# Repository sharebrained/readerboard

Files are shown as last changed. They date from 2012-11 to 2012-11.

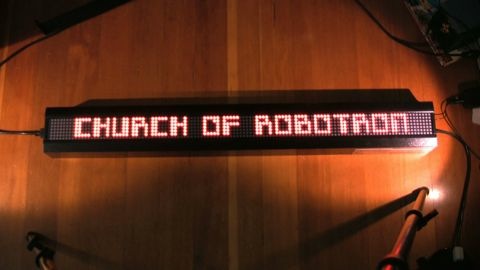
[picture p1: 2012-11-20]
documentation/photos/robotron_readerboard.jpg

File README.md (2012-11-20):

readerboard
===========

Some programmable LED signs have proprietary protocols, relegating these
otherwise fine and useful pieces of hardware to the scrapheap. This project
aims to replace the hardware and software in these signs, giving them new
life.

Readerboard running Church of Robotron

Go troll eBay, buy a "broken" LED sign, and join the party!

Sub-Projects
============

* hardware/readerboard_avr8: Atmel AVR8-based replacement for Data Display
  Corporation controller board.

* firmware/readerboard_avr8: Atmel AVR8-based firmware for USB control of the
  hardware/readerboard_avr8 board.
  
* software/readerboard.py: Example host software for controlling the
  readerboard_avr8 hardware. This was the code that ran at the Church of
  Robotron at ToorCamp 2012.

Status
======

The AVR8-related board, firmware, and software have all been tested and work
well.

Requirements
============

* [EAGLE 5.11 Freeware, Light, Hobbyist, Standard, or Professional]
  (http://www.cadsoftusa.com/shop/pricing/)

Other Projects / Prior Art
==========================

[http://noisybox.net/electronics/LED_sign/]
[http://churchofrobotron.com/]

License
=======

Each sub-project specifies its own license.

Contact
=======

ShareBrained Technology, Inc.

<http://www.sharebrained.com/>

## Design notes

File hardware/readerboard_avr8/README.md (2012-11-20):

readerboard_avr8
================

Replacement controller hardware for interfacing with Data Display Corporation
LED readerboards based on Hitachi 6309 controllers.

Status
======

This board has been fabricated and tested, and works well. It is based on other
stable designs, and a prototype using an Arduino Leonardo.

Bill of Materials
=================

See readerboard_avr8_bom.csv.

Requirements
============

* [EAGLE 5.11 Freeware, Light, Hobbyist, Standard, or Professional]
  (http://www.cadsoftusa.com/shop/pricing/)

Files
=====

* readerboard_avr8.sch:

    Schematic for circuit board, drawn in EAGLE 5.11.

* readerboard_avr8_schematic.pdf:

    Schematic for circuit board, in Adobe PDF format.

* readerboard_avr8_bom.csv:

    List of components used in the circuit board, including recommended
    vendors.

* readerboard_avr8.brd:

    Circuit board layout, drawn in EAGLE 5.11.

* readerboard_avr8_laen2.cam:

    EAGLE CAM file used to generate Gerber RS-274X files for
    circuit board production via
    [Laen's two-layer PCB Order]
    (http://dorkbotpdx.org/wiki/pcb_order).
    
* readerboard_avr8_placements_top.cam

    Diagram of component placements on the top surface of the circuit
    board.
    
License
=======

Copyright (c) 2012, ShareBrained Technology, Inc.
All rights reserved.

This hardware design is licensed under a
[Creative Commons Attribution-ShareAlike 3.0 Unported License]
(http://creativecommons.org/licenses/by-sa/3.0/).

Contact
=======

ShareBrained Technology, Inc.

<http://www.sharebrained.com/>

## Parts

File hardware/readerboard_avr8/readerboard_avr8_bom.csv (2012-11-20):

Ref Des | Qty | Mfr | Mfr Part | Description | Vendor | Vendor Part
C1,2 | 2 | Kemet | C0603C270J5GACTU | CAP CER 27PF 50V 5% NP0 0603 | Digi-Key | 399-1054-1-ND
C3,4 | 2 | Murata | GRM188F51C105ZA01D | CAP CER 1UF 16V Y5V 0603 | Digi-Key | 490-1582-1-ND
C5,6 | 2 | Murata | GRM188F51C104ZA01D | CAP CER .1UF 16V Y5V 0603 | Digi-Key | 490-1577-1-ND
C7,8 |  |  |  | do not populate
F1 | 1 | Bourns | MF-NSMF050-2 | PTC RESETTABLE .50A 13.2V 1206 | Digi-Key | MF-NSMF050-2TR-ND
FB1 | 1 | TDK | MPZ1608S601A | FERRITE CHIP BEAD 600 OHM SMD | Digi-Key | 445-2205-1-ND
J1 | 1 | On Shore Technology | USB-B1KSW6 | CONN USB TYPE B VERTICAL WHITE | Digi-Key | ED2980-ND
J2 | 1 |  |  | 2 x 8 0.1” header
J3 | 1 |  |  | 1 x 3 0.1” header
J4 | 1 |  |  | 2 x 3 0.1” header
J6 | 1 |  |  | 2 x 3 0.1” header
R1,2 | 2 | Yageo | RC0603JR-0722RL | RES 22 OHM 1/10W 5% 0603 SMD | Digi-Key | 311-22GRCT-ND
R9 | 1 | Yageo | RC0603FR-0710KL | RES 10.0K OHM 1/10W 1% 0603 SMD | Digi-Key | 311-10.0KHRCT-ND
U1 | 1 | Atmel | AT90USB162-16AU | MCU AVR USB 16K FLASH 32-TQFP | Digi-Key | AT90USB162-16AU-ND
X1 | 1 | Abracon | ABLS-16.000MHZ-B2-T | CRYSTAL 16.000MHZ 18PF SMD | Digi-Key | 535-9071-1-ND

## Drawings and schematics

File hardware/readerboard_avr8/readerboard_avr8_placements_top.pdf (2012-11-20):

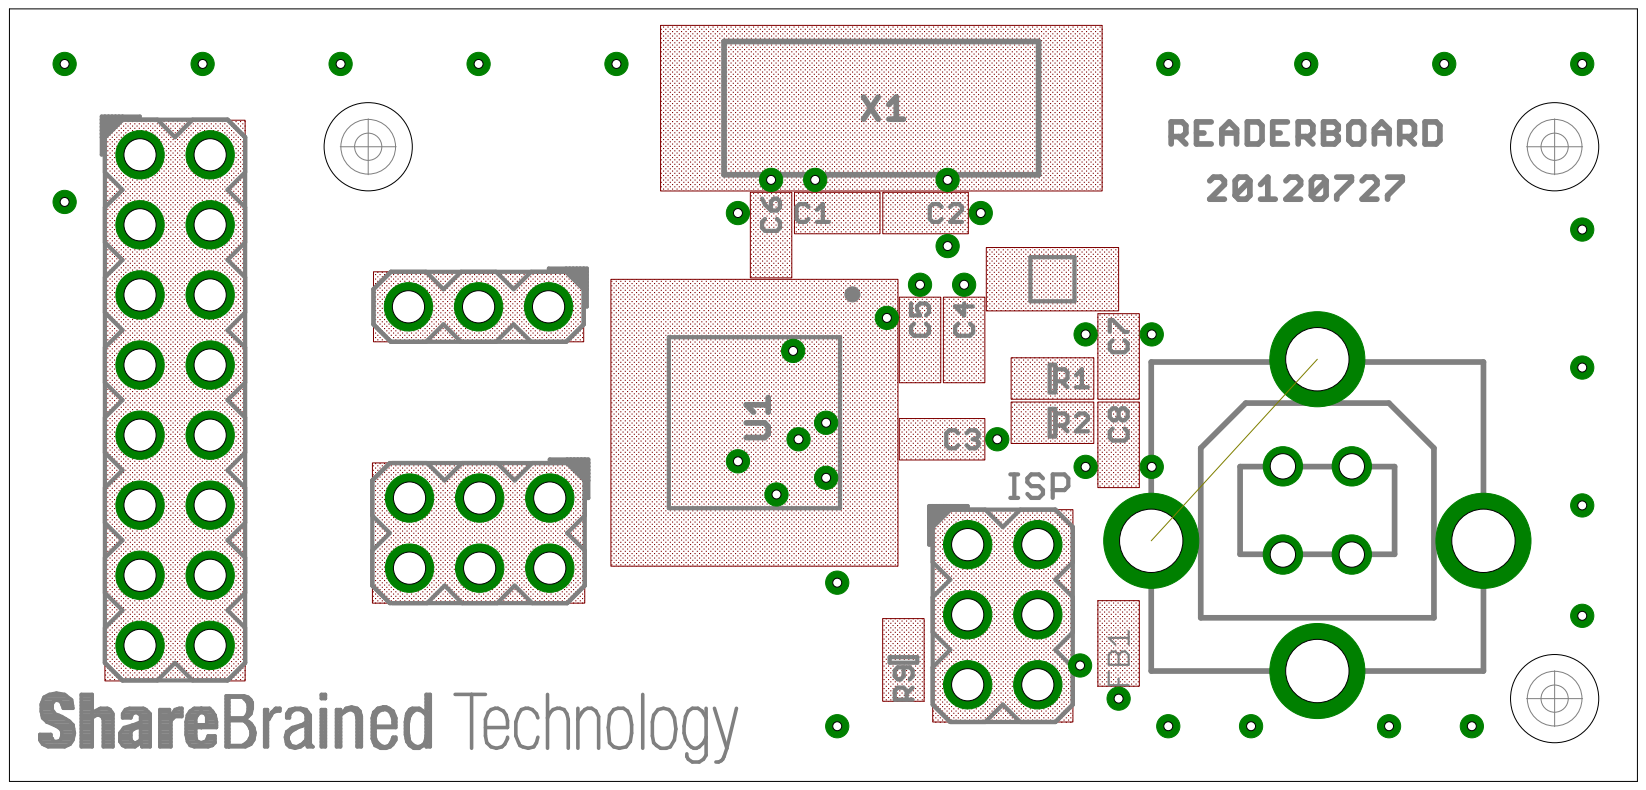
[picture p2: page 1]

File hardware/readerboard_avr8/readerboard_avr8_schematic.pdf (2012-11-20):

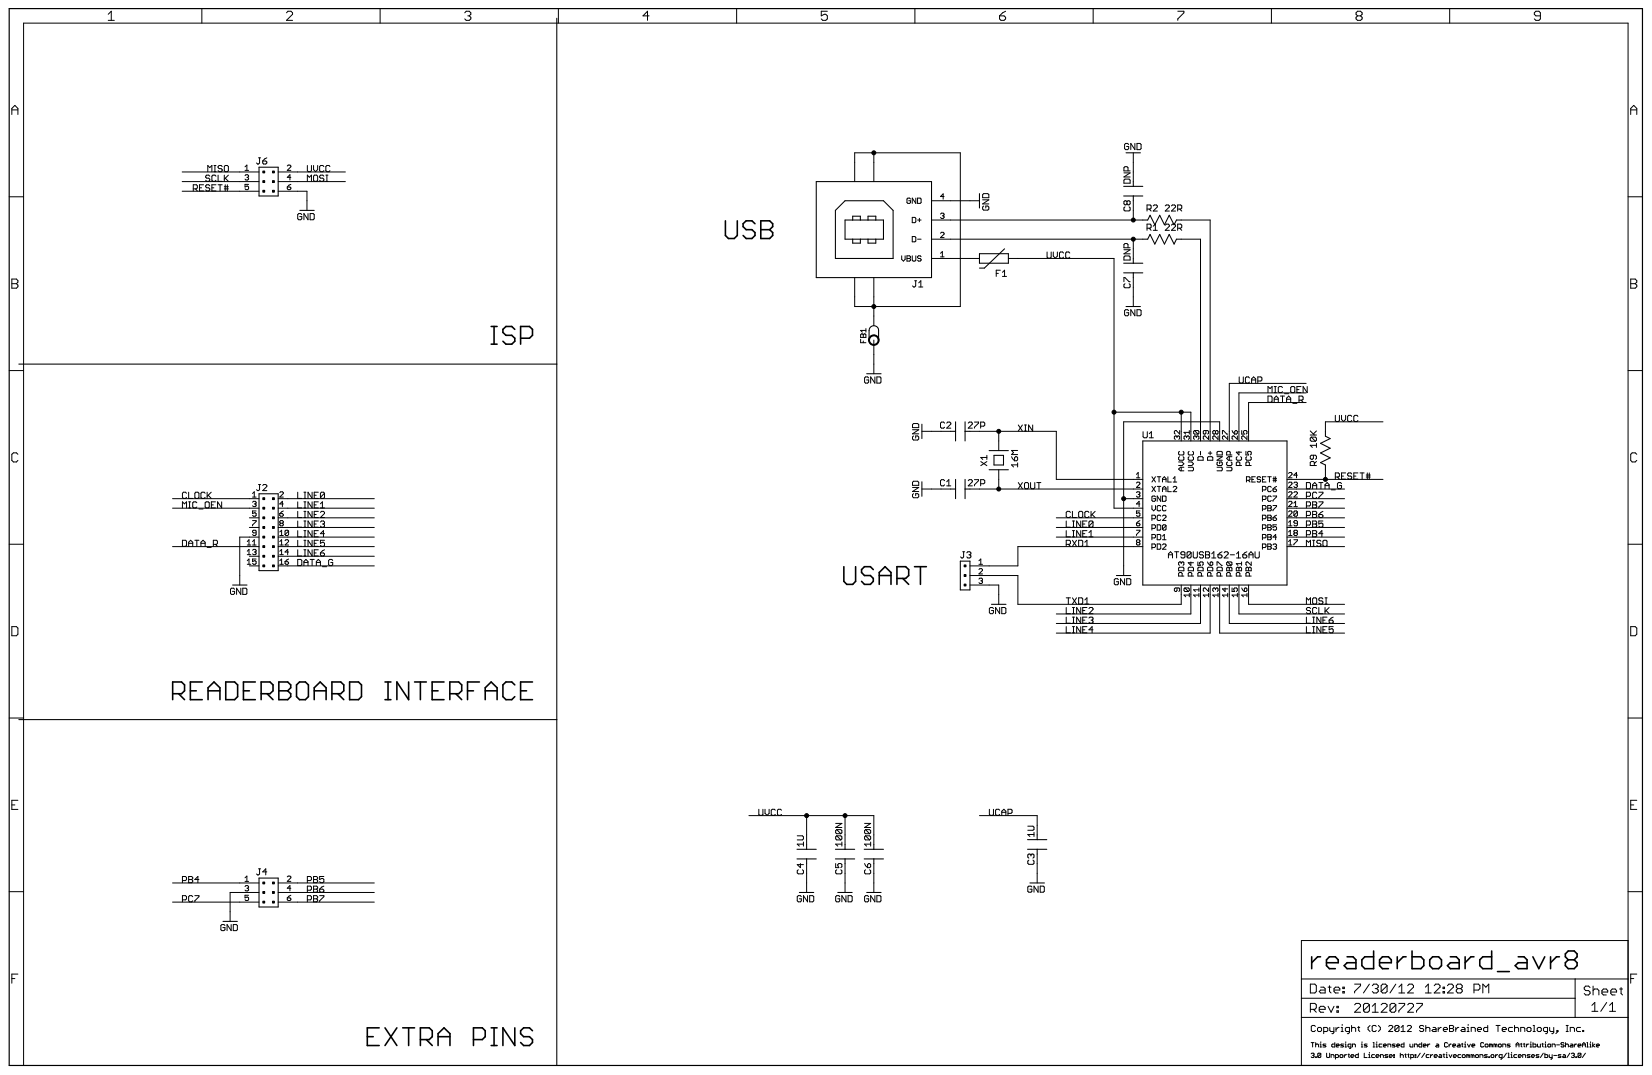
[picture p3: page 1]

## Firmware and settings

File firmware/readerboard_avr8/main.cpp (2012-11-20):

/*
 *
 * Copyright 2012 ShareBrained Technology, Inc.
 *
 * This file is part of readerboard.
 *
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
 */

#include "usb.h"
#include "usb_descriptor.h"

#include <stdint.h>
#include <stdbool.h>

#include <avr/io.h>
#include <avr/interrupt.h>

void Recv(volatile uint8_t* data, uint8_t count) {
	while (count--) {
		*data++ = UEDATX;
	}
}

int USB_RecvControl(void* d, int len)
{
	usb_wait_for_status_out();
	Recv((uint8_t*)d,len);
	usb_clear_out();
	return len;
}

typedef enum {
	DEVICE_STATE_UNINITIALIZED = 0,
	DEVICE_STATE_INITIALIZE_HARDWARE,
	DEVICE_STATE_FETCH_DATA,
	
	DEVICE_STATE_ERROR = 100,
} device_state_t;

#define DEVICE_STATE_FIRST_ERROR (DEVICE_STATE_ERROR)

static volatile device_state_t device_state = DEVICE_STATE_UNINITIALIZED;

static void configure_clocks() {
	/* PLL input prescaler: divide by 2 (16MHz / 2 = 8MHz)
	 */
	PLLCSR = _BV(PLLP0) | _BV(PLLE);
}

static void configure_power() {
	/* On: Timer/Counter0, Timer/Counter1
	 * Off: SPI
	 */
	PRR0 = _BV(PRSPI);
	
	/* On: USB, USART1
	 * Off: (none)
	 */
	//PRR1 = 0;
}

static void configure_pins() {
	MCUCR = 0;
	
	PORTB = 0;
	DDRB = _BV(0);
	
	PORTC = 0;
	DDRC = _BV(6) | _BV(5) | _BV(4) | _BV(2);
	
	PORTD = 0;
	DDRD = _BV(7) | _BV(6) | _BV(5) | _BV(4) | _BV(3) | _BV(1) | _BV(0);
}

static bool configure_hardware() {
	configure_clocks();
	configure_power();
	configure_pins();
	configure_usb();

	// Configure Timer 3 for ~ 60Hz * 7 (420Hz) interrupt rate.
	TCCR1A = 0;
	TCCR1C = 0;
	TCNT1 = 0;
	OCR1A = 38095;
	TIMSK1 = _BV(OCIE1A);
	TCCR1B = _BV(WGM12) | _BV(CS10);

	sei();

	usb_attach();
	
	return true;
}

void strobe_on(const uint8_t i) {
	switch(i) {
	case 0:
		PORTD |= _BV(0);
		break;
		
	case 1:
		PORTD |= _BV(1);
		break;
		
	case 2:
		PORTD |= _BV(4);
		break;
		
	case 3:
		PORTD |= _BV(5);
		break;
		
	case 4:
		PORTD |= _BV(6);
		break;
		
	case 5:
		PORTD |= _BV(7);
		break;
		
	case 6:
		PORTB |= _BV(0);
		break;
		
	default:
		break;
	}
}

void strobe_off(const uint8_t i) {
	switch(i) {
	case 0:
		PORTD &= ~(_BV(0));
		break;
		
	case 1:
		PORTD &= ~(_BV(1));
		break;
		
	case 2:
		PORTD &= ~(_BV(4));
		break;
		
	case 3:
		PORTD &= ~(_BV(5));
		break;
		
	case 4:
		PORTD &= ~(_BV(6));
		break;
		
	case 5:
		PORTD &= ~(_BV(7));
		break;
		
	case 6:
		PORTB &= ~(_BV(0));
		break;
		
	default:
		break;
	}
}

static const uint8_t sign_width = 120;
static const uint8_t sign_height = 7;

static const uint8_t sign_width_bytes = (sign_width + 7) / 8;

uint8_t data_r[2][sign_height][sign_width_bytes]; /* = {
	{
		{ 0xF8, 0x78, 0xF8, 0x78, 0xFC, 0xF8, 0x78, 0xF8, 0x00, 0x00, 0x00, 0x00, 0x00, 0x00, 0x00 },
		{ 0xCC, 0xCC, 0xCC, 0xCC, 0x30, 0xCC, 0xCC, 0xCC, 0x00, 0x00, 0x00, 0x00, 0x00, 0x00, 0x00 },
		{ 0xCC, 0xCC, 0xCC, 0xCC, 0x30, 0xCC, 0xCC, 0xCC, 0x00, 0x00, 0x00, 0x00, 0x00, 0x00, 0x00 },
		{ 0xF8, 0xCC, 0xF8, 0xCC, 0x30, 0xF8, 0xCC, 0xCC, 0x00, 0x00, 0x00, 0x00, 0x00, 0x00, 0x00 },
		{ 0xCC, 0xCC, 0xCC, 0xCC, 0x30, 0xCC, 0xCC, 0xCC, 0x00, 0x00, 0x00, 0x00, 0x00, 0x00, 0x00 },  
		{ 0xCC, 0xCC, 0xCC, 0xCC, 0x30, 0xCC, 0xCC, 0xCC, 0x00, 0x00, 0x00, 0x00, 0x00, 0x00, 0x00 },  
		{ 0xCC, 0x78, 0xF8, 0x78, 0x30, 0xCC, 0x78, 0xCC, 0x00, 0x00, 0x00, 0x00, 0x00, 0x00, 0x00 },
	},
	{
		{ 0xF8, 0x78, 0xF8, 0x78, 0xFC, 0xF8, 0x78, 0xF8, 0x00, 0x00, 0x00, 0x00, 0x00, 0x00, 0x00 },
		{ 0xCC, 0xCC, 0xCC, 0xCC, 0x30, 0xCC, 0xCC, 0xCC, 0x00, 0x00, 0x00, 0x00, 0x00, 0x00, 0x00 },
		{ 0xCC, 0xCC, 0xCC, 0xCC, 0x30, 0xCC, 0xCC, 0xCC, 0x00, 0x00, 0x00, 0x00, 0x00, 0x00, 0x00 },
		{ 0xF8, 0xCC, 0xF8, 0xCC, 0x30, 0xF8, 0xCC, 0xCC, 0x00, 0x00, 0x00, 0x00, 0x00, 0x00, 0x00 },
		{ 0xCC, 0xCC, 0xCC, 0xCC, 0x30, 0xCC, 0xCC, 0xCC, 0x00, 0x00, 0x00, 0x00, 0x00, 0x00, 0x00 },  
		{ 0xCC, 0xCC, 0xCC, 0xCC, 0x30, 0xCC, 0xCC, 0xCC, 0x00, 0x00, 0x00, 0x00, 0x00, 0x00, 0x00 },  
		{ 0xCC, 0x78, 0xF8, 0x78, 0x30, 0xCC, 0x78, 0xCC, 0x00, 0x00, 0x00, 0x00, 0x00, 0x00, 0x00 },
	},
};
*/
/*
uint8_t data_g[2][sign_height][sign_width_bytes]; = {
	{
		{ 0xF8, 0x00, 0x00, 0x00, 0x00, 0x00, 0x00, 0x00, 0x00, 0x00, 0x00, 0x00, 0x00, 0x00, 0x00 },
		{ 0xCC, 0x00, 0x00, 0x00, 0x00, 0x00, 0x00, 0x00, 0x00, 0x00, 0x00, 0x00, 0x00, 0x00, 0x00 },
		{ 0xCC, 0x00, 0x00, 0x00, 0x00, 0x00, 0x00, 0x00, 0x00, 0x00, 0x00, 0x00, 0x00, 0x00, 0x00 },
		{ 0xF8, 0x00, 0x00, 0x00, 0x00, 0x00, 0x00, 0x00, 0x00, 0x00, 0x00, 0x00, 0x00, 0x00, 0x00 },
		{ 0xCC, 0x00, 0x00, 0x00, 0x00, 0x00, 0x00, 0x00, 0x00, 0x00, 0x00, 0x00, 0x00, 0x00, 0x00 },
		{ 0xCC, 0x00, 0x00, 0x00, 0x00, 0x00, 0x00, 0x00, 0x00, 0x00, 0x00, 0x00, 0x00, 0x00, 0x00 },
		{ 0xCC, 0x00, 0x00, 0x00, 0x00, 0x00, 0x00, 0x00, 0x00, 0x00, 0x00, 0x00, 0x00, 0x00, 0x00 },
	},
	{
		{ 0xF8, 0x00, 0x00, 0x00, 0x00, 0x00, 0x00, 0x00, 0x00, 0x00, 0x00, 0x00, 0x00, 0x00, 0x00 },
		{ 0xCC, 0x00, 0x00, 0x00, 0x00, 0x00, 0x00, 0x00, 0x00, 0x00, 0x00, 0x00, 0x00, 0x00, 0x00 },
		{ 0xCC, 0x00, 0x00, 0x00, 0x00, 0x00, 0x00, 0x00, 0x00, 0x00, 0x00, 0x00, 0x00, 0x00, 0x00 },
		{ 0xF8, 0x00, 0x00, 0x00, 0x00, 0x00, 0x00, 0x00, 0x00, 0x00, 0x00, 0x00, 0x00, 0x00, 0x00 },
		{ 0xCC, 0x00, 0x00, 0x00, 0x00, 0x00, 0x00, 0x00, 0x00, 0x00, 0x00, 0x00, 0x00, 0x00, 0x00 },
		{ 0xCC, 0x00, 0x00, 0x00, 0x00, 0x00, 0x00, 0x00, 0x00, 0x00, 0x00, 0x00, 0x00, 0x00, 0x00 },
		{ 0xCC, 0x00, 0x00, 0x00, 0x00, 0x00, 0x00, 0x00, 0x00, 0x00, 0x00, 0x00, 0x00, 0x00, 0x00 },
	},
};
*/
PROGMEM const uint8_t character[64][7] = {
	{ 0b00000000, 0b00000000, 0b00000000, 0b00000000, 0b00000000, 0b00000000 },  // 32 ' '
	{ 0b11000000, 0b11000000, 0b11000000, 0b11000000, 0b00000000, 0b11000000 },  // 33 '!'
	{ 0b10100000, 0b10100000, 0b00000000, 0b00000000, 0b00000000, 0b00000000 },  // 34 '"'
	{ 0b00000000, 0b01010000, 0b11111000, 0b01010000, 0b11111000, 0b01010000 },  // 35 '#'
	{ 0b00100000, 0b11111000, 0b10100000, 0b11111000, 0b00101000, 0b11111000, 0b00100000 },  // 36 '$'
	{ 0b00000000, 0b11001000, 0b11010000, 0b00100000, 0b01011000, 0b10011000 },  // 37 '%'
	{ 0b00000000, 0b00000000, 0b01000000, 0b11100000, 0b01000000, 0b00000000 },  // 38 '+'
	{ 0b10000000, 0b10000000, 0b00000000, 0b00000000, 0b00000000, 0b00000000 },  // 39 '''
	{ 0b00100000, 0b01000000, 0b10000000, 0b10000000, 0b01000000, 0b00100000 },  // 40 '('
	{ 0b10000000, 0b01000000, 0b00100000, 0b00100000, 0b01000000, 0b10000000 },  // 41 ')'
	{ 0b00000000, 0b10001000, 0b01010000, 0b00100000, 0b01010000, 0b10001000 },  // 42 '*'
	{ 0b00000000, 0b00100000, 0b00100000, 0b11111000, 0b00100000, 0b00100000 },  // 43 '+'
	{ 0b00000000, 0b00000000, 0b00000000, 0b00000000, 0b11000000, 0b11000000, 0b01000000 },  // 44 ','
	{ 0b00000000, 0b00000000, 0b11111000, 0b00000000, 0b00000000, 0b00000000 },  // 45 '-'
	{ 0b00000000, 0b00000000, 0b00000000, 0b00000000, 0b11000000, 0b11000000 },  // 46 '.'
	{ 0b00001000, 0b00010000, 0b00100000, 0b01000000, 0b10000000, 0b00000000 },  // 47 '/'
	{ 0b11111000, 0b10001000, 0b10001000, 0b10001000, 0b10001000, 0b11111000 },  // 48 '0'
	{ 0b01100000, 0b00100000, 0b00100000, 0b00100000, 0b00100000, 0b11110000 },  // 49 '1'
	{ 0b01111000, 0b00001000, 0b11111000, 0b10000000, 0b10000000, 0b11110000 },  // 50 '2'
	{ 0b01111000, 0b00001000, 0b01111000, 0b00001000, 0b00001000, 0b11111000 },  // 51 '3'
	{ 0b10000000, 0b10010000, 0b10010000, 0b11111000, 0b00010000, 0b00010000 },  // 52 '4'
	{ 0b11110000, 0b10000000, 0b11111000, 0b00001000, 0b00001000, 0b11111000 },  // 53 '5'
	{ 0b11110000, 0b10000000, 0b11111000, 0b10001000, 0b10001000, 0b11111000 },  // 54 '6'
	{ 0b11111000, 0b00001000, 0b00010000, 0b00100000, 0b01000000, 0b10000000 },  // 55 '7'
	{ 0b11111000, 0b10001000, 0b11111000, 0b10001000, 0b10001000, 0b11111000 },  // 56 '8'
	{ 0b11111000, 0b10001000, 0b11111000, 0b00001000, 0b00001000, 0b01111000 },  // 57 '9'
	{ 0b00000000, 0b11000000, 0b11000000, 0b00000000, 0b11000000, 0b11000000 },  // 58 ':'
	{ 0b00000000, 0b11000000, 0b11000000, 0b00000000, 0b11000000, 0b11000000, 0b01000000 },  // 59 ';'
	{ 0b00100000, 0b01000000, 0b10000000, 0b01000000, 0b00100000, 0b00000000 },  // 60 '<'
	{ 0b00000000, 0b11111000, 0b00000000, 0b11111000, 0b00000000, 0b00000000 },  // 61 '='
	{ 0b00000000, 0b10000000, 0b01000000, 0b00100000, 0b01000000, 0b10000000 },  // 62 '>'
	{ 0b01100000, 0b10010000, 0b00110000, 0b01100000, 0b00000000, 0b01100000 },  // 63 '?'
	{ 0b01000000, 0b10100000, 0b11100000, 0b00000000, 0b11100000, 0b01000000 },  // 64 '@'
	{ 0b11111000, 0b10011000, 0b11111000, 0b10011000, 0b10011000, 0b10011000 },  // 65 'A'
	{ 0b11110000, 0b10010000, 0b11111000, 0b11001000, 0b11001000, 0b11111000 },  // 66 'B'
	{ 0b11111000, 0b11000000, 0b11000000, 0b11000000, 0b11000000, 0b11111000 },  // 67 'C'
	{ 0b11110000, 0b11001000, 0b11001000, 0b11001000, 0b11001000, 0b11110000 },  // 68 'D'
	{ 0b11111000, 0b10000000, 0b11111000, 0b11000000, 0b11000000, 0b11111000 },  // 69 'E'
	{ 0b11111000, 0b10000000, 0b11111000, 0b11000000, 0b11000000, 0b11000000 },  // 70 'F'
	{ 0b11111000, 0b11011000, 0b11000000, 0b11011000, 0b11001000, 0b11111000 },  // 71 'G'
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
};

PROGMEM const uint8_t character_attr[64][3] = {
	{ 0, 0, 4 },  // 32 ' '
	{ 2, 7, 4 },  // 33 '!'
	{ 3, 7, 5 },  // 34 '"'
	{ 5, 7, 7 },  // 35 '#'
	{ 5, 7, 7 },  // 36 '$'
	{ 5, 7, 7 },  // 37 '%'
	{ 3, 7, 5 },  // 38 '+'
	{ 1, 7, 3 },  // 39 '''
	{ 3, 7, 5 },  // 40 '('
	{ 3, 7, 5 },  // 41 ')'
	{ 5, 7, 7 },  // 42 '*'
	{ 5, 7, 7 },  // 43 '+'
	{ 2, 7, 4 },  // 44 ','
	{ 5, 7, 7 },  // 45 '-'
	{ 2, 7, 4 },  // 46 '.'
	{ 5, 7, 7 },  // 47 '/'
	{ 5, 7, 6 },  // 48 '0'
	{ 4, 7, 6 },  // 49 '1'
	{ 5, 7, 6 },  // 50 '2'
	{ 5, 7, 6 },  // 51 '3'
	{ 5, 7, 6 },  // 52 '4'
	{ 5, 7, 6 },  // 53 '5'
	{ 5, 7, 6 },  // 54 '6'
	{ 5, 7, 6 },  // 55 '7'
	{ 5, 7, 6 },  // 56 '8'
	{ 5, 7, 6 },  // 57 '9'
	{ 2, 7, 4 },  // 58 ':'
	{ 2, 7, 4 },  // 59 ';'
	{ 3, 7, 5 },  // 60 '<'
	{ 5, 7, 7 },  // 61 '='
	{ 3, 7, 5 },  // 62 '>'
	{ 4, 7, 6 },  // 63 '?'
	{ 3, 7, 5 },  // 64 '@'
	{ 5, 7, 6 },  // 65 'A'
	{ 5, 7, 6 },  // 66 'B'
	{ 5, 7, 6 },  // 67 'C'
	{ 5, 7, 6 },  // 68 'D'
	{ 5, 7, 6 },  // 69 'E'
	{ 5, 7, 6 },  // 70 'F'
	{ 5, 7, 6 },  // 71 'G'
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
};

void blit(const uint8_t* const source,
	const uint8_t source_width_bytes,
	const uint8_t s_x1, const uint8_t s_y1,
	const uint8_t s_x2, const uint8_t s_y2,
	uint8_t* const target,
	const uint8_t target_width_bytes,
	const uint8_t t_x1, const uint8_t t_y1) {

	uint8_t s_y = s_y1;
	uint8_t t_y = s_y1;
	for(; (s_y<s_y2) && (t_y<sign_height); s_y++, t_y++) {
		uint8_t s_x = s_x1;
		uint8_t t_x = t_x1;
		for(; (s_x<s_x2) && (t_x<sign_width); s_x++, t_x++) {
			const uint8_t* const source_address = &source[(s_x >> 3) + s_y * source_width_bytes];
			const uint8_t pixel_value = (pgm_read_byte(source_address) >> ((s_x & 7) ^ 7)) & 1;

			uint8_t* const target_address = &target[(t_x >> 3) + t_y * target_width_bytes];
			const uint8_t target_mask = 1 << ((t_x & 7) ^ 7);

			if( pixel_value ) {
				*target_address |= target_mask;
			} else {
				*target_address &= ~target_mask;
			}
		}
	}
}

void draw_text(const uint8_t buffer_n, uint8_t x, uint8_t y, const char* message) {
	while( *message != 0 ) {
		char c = *(message++);
		if( (c < 32) || (c > 95) ) {
			c = ' ';
		}
		const uint8_t char_index = c - 32;
		const uint8_t character_width = pgm_read_byte(&character_attr[char_index][0]);
		const uint8_t character_height = pgm_read_byte(&character_attr[char_index][1]);
		blit(
			character[char_index], (character_width + 7) >> 3,
			0, 0, character_width, character_height,
			data_r[buffer_n][0], sign_width_bytes,
			x, y
		);
		const uint8_t character_spacing = pgm_read_byte(&character_attr[char_index][2]);
		x += character_spacing;
	}
}

#define CLOCK_BIT (1 << 2)
#define R_BIT (1 << 5)
#define G_BIT (1 << 6)

volatile uint8_t current_buffer = 0;
/*
#define SEND_BIT(bit_number) \
	__asm__ __volatile__ ( \
		"bst  %[r], %[n]\n\t" \
		"bld  %[value], 6\n\t" \
		"bst  %[g], %[n]\n\t" \
		"bld  %[value], 7\n\t" \
		"out  %[port], %[value]\n\t" \
		"sbi  %[port], 5\n\t" \
		: \
		: [port] "I" (_SFR_IO_ADDR(PORTB)), \
		[value] "r" (port_b), \
		[r] "r" (r), \
		[g] "r" (g), \
		[n] "I" (bit_number) \
		: "r0" \
	)
*/
#define SEND_BIT(bit_number) \
	__asm__ __volatile__ ( \
		"bst  %[r], %[n]\n\t" \
		"bld  %[value], 5\n\t" \
		"out  %[port], %[value]\n\t" \
		"sbi  %[port], 2\n\t" \
		: \
		: [port] "I" (_SFR_IO_ADDR(PORTC)), \
		[value] "r" (port_c), \
		[r] "r" (r), \
		[n] "I" (bit_number) \
		: "r0" \
	)

volatile bool frame_sync;

ISR(TIMER1_COMPA_vect) {
	static uint8_t current_row = 0;

	strobe_off(current_row);
	current_row = current_row + 1;
	if( current_row >= sign_height ) {
		current_row = 0;
	}
	
	const uint8_t* rp = (const uint8_t*)&data_r[current_buffer][current_row];
	
	for(uint8_t col=0; col<sign_width_bytes; col++) {
		const uint8_t r = *(rp++);
		const uint8_t port_c = PORTC & (~CLOCK_BIT);

		SEND_BIT(7);
		SEND_BIT(6);
		SEND_BIT(5);
		SEND_BIT(4);
		SEND_BIT(3);
		SEND_BIT(2);
		SEND_BIT(1);
		SEND_BIT(0);
	}
	
	strobe_on(current_row);
	
	if( current_row == (sign_height - 1) ) {
		frame_sync = true;
	}
}

typedef struct {
	void* state;
	bool (*update_fn)(void* const state);
} animation_t;

animation_t animation = {
	0, 0
};

typedef struct {
	uint8_t frame_count;
	uint8_t frames_per_pixel;
	uint8_t pixels_remaining;
} scroll_h_t;

void scroll_h_init(void* const sv, const uint8_t frames_per_pixel, const uint8_t pixels_remaining) {
	scroll_h_t* const state = (scroll_h_t* const)sv;
	state->frame_count = 0;
	state->frames_per_pixel = frames_per_pixel;
	state->pixels_remaining = pixels_remaining;
}

bool scroll_left_update(void* const sv) {
	scroll_h_t* const state = (scroll_h_t* const)sv;
	const uint_fast8_t buffer = current_buffer;
	if( state->pixels_remaining > 0 ) {
		if( state->frame_count >= state->frames_per_pixel ) {
			state->frame_count = 0;
			state->pixels_remaining -= 1;
			for(uint_fast8_t y=0; y<sign_height; y++) {
				uint8_t* p = &data_r[buffer][y][sign_width_bytes];
				uint8_t r = 0;
				__asm__ __volatile__ ( \
					"clc\n\t" \
					"ld   %[r], -%a1\n\t" \
					"rol  %[r]\n\t" \
					"st   %a1, %[r]\n\t" \
					"ld   %[r], -%a1\n\t" \
					"rol  %[r]\n\t" \
					"st   %a1, %[r]\n\t" \
					"ld   %[r], -%a1\n\t" \
					"rol  %[r]\n\t" \
					"st   %a1, %[r]\n\t" \
					"ld   %[r], -%a1\n\t" \
					"rol  %[r]\n\t" \
					"st   %a1, %[r]\n\t" \
					"ld   %[r], -%a1\n\t" \
					"rol  %[r]\n\t" \
					"st   %a1, %[r]\n\t" \
					"ld   %[r], -%a1\n\t" \
					"rol  %[r]\n\t" \
					"st   %a1, %[r]\n\t" \
					"ld   %[r], -%a1\n\t" \
					"rol  %[r]\n\t" \
					"st   %a1, %[r]\n\t" \
					"ld   %[r], -%a1\n\t" \
					"rol  %[r]\n\t" \
					"st   %a1, %[r]\n\t" \
					"ld   %[r], -%a1\n\t" \
					"rol  %[r]\n\t" \
					"st   %a1, %[r]\n\t" \
					"ld   %[r], -%a1\n\t" \
					"rol  %[r]\n\t" \
					"st   %a1, %[r]\n\t" \
					"ld   %[r], -%a1\n\t" \
					"rol  %[r]\n\t" \
					"st   %a1, %[r]\n\t" \
					"ld   %[r], -%a1\n\t" \
					"rol  %[r]\n\t" \
					"st   %a1, %[r]\n\t" \
					"ld   %[r], -%a1\n\t" \
					"rol  %[r]\n\t" \
					"st   %a1, %[r]\n\t" \
					"ld   %[r], -%a1\n\t" \
					"rol  %[r]\n\t" \
					"st   %a1, %[r]\n\t" \
					"ld   %[r], -%a1\n\t" \
					"rol  %[r]\n\t" \
					"st   %a1, %[r]\n\t" \
					: \
					: [r] "r" (r), \
					[p] "e" (p) \
					: "r0" \
				);
			}
		} else {
			state->frame_count += 1;
		}
		return true;
	}

	return false;
}

bool scroll_right_update(void* const sv) {
	scroll_h_t* const state = (scroll_h_t* const)sv;
	const uint_fast8_t buffer = current_buffer;
	if( state->pixels_remaining > 0 ) {
		if( state->frame_count >= state->frames_per_pixel ) {
			state->frame_count = 0;
			state->pixels_remaining -= 1;
			for(uint_fast8_t y=0; y<sign_height; y++) {
				uint8_t* p = &data_r[buffer][y][0];
				uint8_t r = 0;
				__asm__ __volatile__ ( \
					"clc\n\t" \
					"ld   %[r], %a1\n\t" \
					"ror  %[r]\n\t" \
					"st   %a1+, %[r]\n\t" \
					"ld   %[r], %a1\n\t" \
					"ror  %[r]\n\t" \
					"st   %a1+, %[r]\n\t" \
					"ld   %[r], %a1\n\t" \
					"ror  %[r]\n\t" \
					"st   %a1+, %[r]\n\t" \
					"ld   %[r], %a1\n\t" \
					"ror  %[r]\n\t" \
					"st   %a1+, %[r]\n\t" \
					"ld   %[r], %a1\n\t" \
					"ror  %[r]\n\t" \
					"st   %a1+, %[r]\n\t" \
					"ld   %[r], %a1\n\t" \
					"ror  %[r]\n\t" \
					"st   %a1+, %[r]\n\t" \
					"ld   %[r], %a1\n\t" \
					"ror  %[r]\n\t" \
					"st   %a1+, %[r]\n\t" \
					"ld   %[r], %a1\n\t" \
					"ror  %[r]\n\t" \
					"st   %a1+, %[r]\n\t" \
					"ld   %[r], %a1\n\t" \
					"ror  %[r]\n\t" \
					"st   %a1+, %[r]\n\t" \
					"ld   %[r], %a1\n\t" \
					"ror  %[r]\n\t" \
					"st   %a1+, %[r]\n\t" \
					"ld   %[r], %a1\n\t" \
					"ror  %[r]\n\t" \
					"st   %a1+, %[r]\n\t" \
					"ld   %[r], %a1\n\t" \
					"ror  %[r]\n\t" \
					"st   %a1+, %[r]\n\t" \
					"ld   %[r], %a1\n\t" \
					"ror  %[r]\n\t" \
					"st   %a1+, %[r]\n\t" \
					"ld   %[r], %a1\n\t" \
					"ror  %[r]\n\t" \
					"st   %a1+, %[r]\n\t" \
					"ld   %[r], %a1\n\t" \
					"ror  %[r]\n\t" \
					"st   %a1+, %[r]\n\t" \
					: \
					: [r] "r" (r), \
					[p] "e" (p) \
					: "r0" \
				);
			}
		} else {
			state->frame_count += 1;
		}
		return true;
	}

	return false;
}

scroll_h_t scroll_h;

/////////////////////////////////////////////////////////////////////////

bool usb_set_line(const usb_setup_t& setup) {
	const uint8_t buffer = setup.bRequest;
	uint8_t length = setup.wLength_L;
	if( buffer < 2 ) {
		usb_wait_for_status_out();
		uint8_t plane = UEDATX;
		if( plane == 0 ) {
			uint8_t row = UEDATX;
			if( row < sign_height ) {
				length -= 2;
				if( length <= sign_width_bytes ) {
					Recv((uint8_t*)&data_r[buffer][row], length);
					usb_clear_out();
					return true;
				}
			}
		}
	}

	return false;
}

bool usb_show_buffer(const uint8_t buffer) {
	if( (buffer == 0) || (buffer == 1) ) {
		current_buffer = buffer;
		return true;
	}

	return false;
}

bool usb_clear_buffer(const uint8_t buffer) {
	if( buffer < 2 ) {
		uint8_t* rp = (uint8_t*)&data_r[buffer];
		//uint8_t* gp = (uint8_t*)&data_g[buffer];
		for(uint8_t i=0; i<sizeof(data_r[buffer]); i++) {
			*(rp++) = 0;
			//*(gp++) = 0;
		}
		return true;
	}

	return false;
}

typedef struct {
	uint8_t x, y;
	char message[32];
} usb_draw_text_t;

bool usb_draw_text(const usb_setup_t& setup) {
	const uint8_t buffer = setup.wValue_L;
	uint8_t length = setup.wLength_L;

	usb_draw_text_t data;
	USB_RecvControl(&data, length);

	if( buffer < 2 ) {
		data.message[length - 2] = 0;
		draw_text(buffer, data.x, data.y, &data.message[0]);
		return true;
	}

	return false;
}

typedef struct {
	uint8_t frames_per_pixel;
	uint8_t pixel_count;
} usb_animate_scroll_h_t;

bool usb_animate_scroll_left(const usb_setup_t& setup) {
	const uint8_t buffer = setup.wValue_L;
	uint8_t length = setup.wLength_L;

	usb_animate_scroll_h_t data;
	USB_RecvControl(&data, length);

	if( buffer < 2 ) {
		if( animation.update_fn == 0 ) {
			scroll_h_init(&scroll_h, data.frames_per_pixel, data.pixel_count);
			animation.state = &scroll_h;
			animation.update_fn = scroll_left_update;
		}
		// TODO: Error if animation in progress?
		return true;
	}

	return false;
}

bool usb_animate_scroll_right(const usb_setup_t& setup) {
	const uint8_t buffer = setup.wValue_L;
	uint8_t length = setup.wLength_L;

	usb_animate_scroll_h_t data;
	USB_RecvControl(&data, length);

	if( buffer < 2 ) {
		if( animation.update_fn == 0 ) {
			scroll_h_init(&scroll_h, data.frames_per_pixel, data.pixel_count);
			animation.state = &scroll_h;
			animation.update_fn = scroll_right_update;
		}
		// TODO: Error if animation in progress?
		return true;
	}

	return false;
}

bool usb_handle_vendor_request(const usb_setup_t& setup) {
	switch( setup.bRequest ) {
	case 0:
	case 1:
		return usb_set_line(setup);

	case 2:
		return usb_show_buffer(setup.wValue_L);

	case 3:
		return usb_clear_buffer(setup.wValue_L);

	case 4:
		return usb_draw_text(setup);

	case 5:
		return usb_animate_scroll_left(setup);

	case 6:
		return usb_animate_scroll_right(setup);

	default:
		return false;
	}
}

void animate() {
	while( frame_sync != true );
	frame_sync = false;

	if( animation.update_fn != 0 ) {
		if( animation.update_fn(animation.state) == false ) {
			animation.update_fn = 0;
			animation.state = 0;
		}
	}
}

int main() {
	while(1) {
		switch(device_state) {
		case DEVICE_STATE_UNINITIALIZED:
			device_state = DEVICE_STATE_INITIALIZE_HARDWARE;
			break;
			
		case DEVICE_STATE_INITIALIZE_HARDWARE:
			if( configure_hardware() ) {
				device_state = DEVICE_STATE_FETCH_DATA;
			} else {
				device_state = DEVICE_STATE_ERROR;
			}
			break;

		case DEVICE_STATE_FETCH_DATA:
			animate();
			break;

		case DEVICE_STATE_ERROR:
		default:
		while(true);
		}
	}
	
	return 0;
}

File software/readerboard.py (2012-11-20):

#!/usr/bin/env python

# Copyright 2012 ShareBrained Technology, Inc.
#
# This file is part of readerboard.
#
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
import usb
import time
import struct
import csv

class Readerboard(object):
    led_req_type = (0 << 7) | (2 << 5) | (0 << 0)
    
    def __init__(self):
        self.device = usb.core.find(idVendor=0x8080, idProduct=0x6464)
        self.device.set_configuration()
        self.cfg = self.device.get_active_configuration()
        self.intf = self.cfg[(0, 0)]
        self.back_buffer = 0

    def set_line(self, row, data_r, data_g, buffer_n=None):
        buffer_n = self.back_buffer if buffer_n is None else buffer_n
        if buffer_n not in (0, 1):
            raise RuntimeError("set_line: invalid buffer_n value: " + buffer_n)
        data = struct.pack("BB", 0, row) + data_r
        self.device.ctrl_transfer(self.led_req_type, buffer_n, 0, 0, data)
        #self.device.ctrl_transfer(self.led_req_type, buffer_n, 0x100 | row, 0, data_g)

    def show_buffer(self, buffer_n=None):
        buffer_n = self.back_buffer if buffer_n is None else buffer_n
        self.device.ctrl_transfer(self.led_req_type, 2, buffer_n, 0)
        self.back_buffer = 1 - buffer_n

    def clear_buffer(self, buffer_n=None):
        buffer_n = self.back_buffer if buffer_n is None else buffer_n
        self.device.ctrl_transfer(self.led_req_type, 3, buffer_n, 0)
    
    def draw_text(self, x, y, message, buffer_n=None):
        buffer_n = self.back_buffer if buffer_n is None else buffer_n
        data = struct.pack("BB", x, y) + message
        self.device.ctrl_transfer(self.led_req_type, 4, buffer_n, 0, data)
        
    def scroll_left(self, frames_per_pixel, pixel_count, buffer_n=None):
        buffer_n = self.back_buffer if buffer_n is None else buffer_n
        data = struct.pack("BB", frames_per_pixel, pixel_count)
        self.device.ctrl_transfer(self.led_req_type, 5, buffer_n, 0, data)

    def scroll_right(self, frames_per_pixel, pixel_count, buffer_n=None):
        buffer_n = self.back_buffer if buffer_n is None else buffer_n
        data = struct.pack("BB", frames_per_pixel, pixel_count)
        self.device.ctrl_transfer(self.led_req_type, 6, buffer_n, 0, data)

def read_leaderboard():
    f = csv.reader(open('/home/mutant/mcor/leaderboard/data/leaderboard.txt', 'r'))
    result = []
    for row in f:
        d = {
            'initials': row[0],
            'score': int(row[1]),
        }
        result.append(d)
    return tuple(sorted(result, lambda x, y: cmp(y['score'], x['score'])))

def message_sequence(board, score_data):
    board.clear_buffer()
    board.draw_text(9, 0, "CHURCH OF ROBOTRON")
    board.show_buffer()
    time.sleep(1.0)
    board.scroll_left(0, 120)
    time.sleep(3.0)
    
    board.clear_buffer()
    board.draw_text(32, 0, "INSERT COIN")
    board.show_buffer()
    time.sleep(2.0)

    for i in range(5):
        board.clear_buffer()
        board.draw_text(0, 0, "PREPARE FOR JUDGEMENT")
        board.show_buffer()
        time.sleep(0.3)
        board.clear_buffer()
        board.show_buffer()
        time.sleep(0.3)

    board.clear_buffer()
    board.show_buffer()
    time.sleep(1.0)

    if score_data:    
        board.clear_buffer()
        board.draw_text(24, 0, "MUTANT SAVIOR")
        board.show_buffer()
        time.sleep(2.0)
    
        board.clear_buffer()
        board.draw_text(24, 0, "TOP CANDIDATE")
        board.show_buffer()
        time.sleep(2.0)
    
        board.clear_buffer()
        d = score_data[0]
        board.draw_text(32, 0, "%(score)s %(initials)s" % d)
        board.show_buffer()
        time.sleep(2.0)
        board.scroll_right(0, 120)
        time.sleep(3.0)

score_data = None

while True:
    try:
        board = Readerboard()
        #score_data = read_leaderboard()
        message_sequence(board, score_data)
    except Exception, e:
        print(e)
        time.sleep(5.0)

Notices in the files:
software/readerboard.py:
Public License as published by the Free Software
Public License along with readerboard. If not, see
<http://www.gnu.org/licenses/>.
